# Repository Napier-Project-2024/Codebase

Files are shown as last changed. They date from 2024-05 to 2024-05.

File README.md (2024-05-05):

# Hexasense API v0.1

This repository contains the component parts of the prototype implementation of a proprioception system for the Vincross HEXA robot.
<br>
<br>
This project is developed by Group Project Team 104 on behalf of the We Are Robots Lab at Edinburgh Napier University as part of the Group Project Module 2023-24.
<br>
<br>
See [Hexasense Hardware](/Hexasense_Hardware) for the Hexasense Hardware implementation
<br>
See [Hexasense API](/Hexasense_API) for the Hexasense API implementation
<br>
See [Demo](/Demo) for a usage demonstration MIND SDK Project for the HEXA robot

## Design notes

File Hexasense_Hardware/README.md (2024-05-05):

# Hexasense API v0.1 - Hardware Implementation

This seems like it's going to be a dense document so, if you don't have one already, get yourself a coffee first.

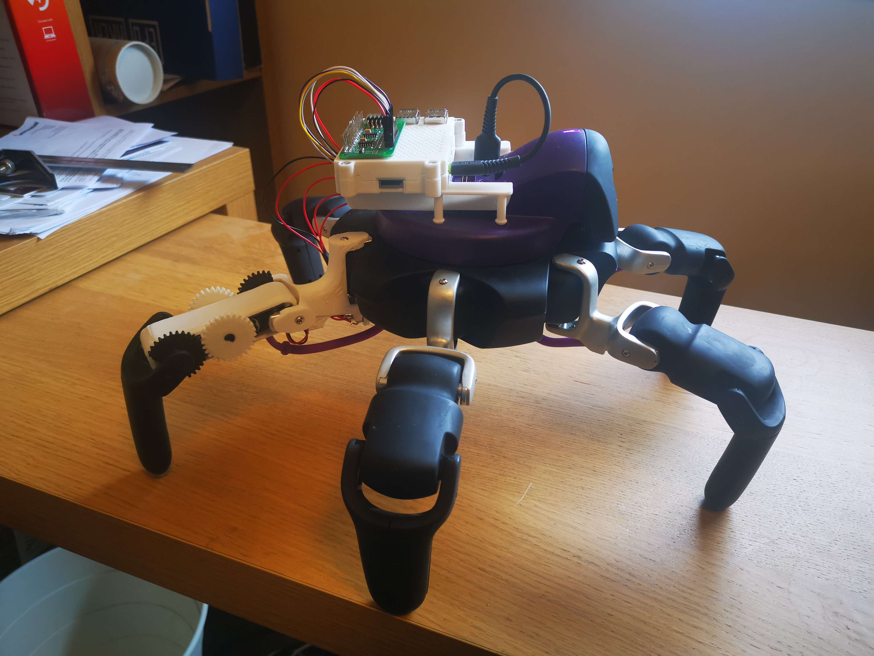
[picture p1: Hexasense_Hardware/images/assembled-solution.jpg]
Assembled Prototype


## Design Intent

The intention of this hardware design is to provide a means of sensing the position of the actuators of the HEXA robot whilst maintaining the ability to fully revert the robot to it's original factory state.<br>
Any instance where modification of the robot's hardware would be required, an appropriate 3D printed part has been designed and manufactured to integrate in place of the original robot hardware.<br>
It is also intended that the SBC component part of this system should function as an analogue for the HEXA robot to allow future integration of the Hexasense API software solution and ADC system directly with the HEXA robot itself, negating the need for the additional SBC hardware and potentially increasing the responsiveness of the API in use.<br>

## Hardware Description

The hardware implementation to add a proprioceptive sensing system to the HEXA Robot can be described as having three component parts to it's structure.
- A "Digital Twin" Data Processing & Relay System - Comprising of an off-the-shelf Raspberry Pi 4B SBC
- An ADC Measurement System - Comprising of a series of potentiometers mechanically coupled to the robot's actuators and an off-the-shelf ADC printed circuit board interfaced with the Data Processing & Relay System using the I2C protocol
- The Mechanical Hardware Assembly - A series of plastic parts manufactured using an FDM rapid prototyping process and designed to integrate the sensing system with the robot's hardware

These three component parts function together to deliver the desired actuator positional data required by the project.

### Raspberry Pi 4B SBC - The "Digital Twin"

This small single board computer provides a method of capturing the sensing data from the I2C bus and relaying it to the HEXA robot.
The SBC is configured to detect and connect to the HEXA robot's wifi access point automatically and begin broadcasting the sensing data through a network accessible implementation of the python fastAPI library. This will allow the API to be called by a Golang script in order to make use of the sensing data for proprioceptive purposes.

For detailed documentation of the Raspberry Pi 4B, please see the [Raspberry Pi 4B Documentation.](https://www.raspberrypi.com/documentation/computers/raspberry-pi.html)

### ADC Pi - Measurement System

The ADC Pi board is comprised of two MCP3424 ADC ICs and an bi-directional I2C Logic Level converter circuit which converts the Raspberry Pi's 3.3 volt logic level to
a 5 volt logic level suitbale for the MCP3424 ADCs. The ADCs can be queried by the Rapserry Pi over the I2C buss and will return the voltage value present
at each of it's sense pins.

For detailed documentation of the ADC Pi add-on board, please see the [AB Electronics](https://www.abelectronics.co.uk/) website for the [ADC Pi product.](https://www.abelectronics.co.uk/p/69/adc-pi)

### Potentiometers - Actuator Coupling

The prototype implementation uses three TT Electronics P090L-01F15BR10K 10 kilo-ohm linear potentiometers which function as voltage dividers. Each potentiometer has their CW and CCW pins tied to 5 volts and Ground respectively, while their W pin is tied to the respective sense pin of the ADC Pi baord. This allows for the rotation of the potentiometer to result in a change in voltage detected by the ADC IC as a voltage value between the 5 volts and 0 volts.

In principle, any value of potentiometer can be used in this manner, however it is important that the potentiometer selected has a Linear taper type, such that the voltage returned to the ADC at each rotational position of the potentiometer is proportional to the degree of rotation of the potentiometer, allowing the angle of 
rotation to be calculated accurately.

For detailed documentation of the TT Electronics P090L-01F15BR10K potentiometers, please see the TT Electronics [Product Page](https://www.ttelectronics.com/products/passive-components/potentiometers/p090l/) and [Datasheet.](https://www.ttelectronics.com/TTElectronics/media/ProductFiles/Datasheet/P090.pdf)

## Schematic Diagram of Electronic Components

This section describes the electronic connections between the component parts of the system only. 
For detailed schematic diagrams of the individual component parts of the system, please see the individual manufacturer's documentation and datasheets as directed above.

### Connecting the Raspberry Pi to the ADC Pi

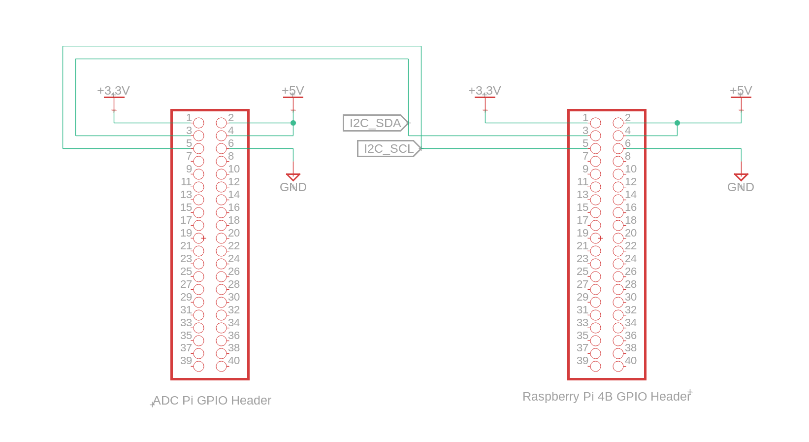
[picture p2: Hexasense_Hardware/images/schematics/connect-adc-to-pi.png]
Connecting the Raspberry Pi to the ADC Pi


The above schematic shows the connections required between the Raspberry Pi SBD and the ADC Pi add-on board for correct operation. 

Although both devices have 40-pin connectors, this is merely for the convenience of direct physical connection during development. In use, only five pin connections are required for correct interoperation of the devices.
The ADC Pi requires both 5v and 3.3v, as well as Ground connections to power the ADC ICs and the 3.3v to 5v logic level converters (as illustrated in the ADC Pi's board schematic). 
Data connection between the two devices is achieved using the I2C0 bus of the Raspberry Pi using the I2C0_SDA (pin 3) and I2C0_SDL (pin 5) connections.

### ADC Pi I2C Bus Address Setting

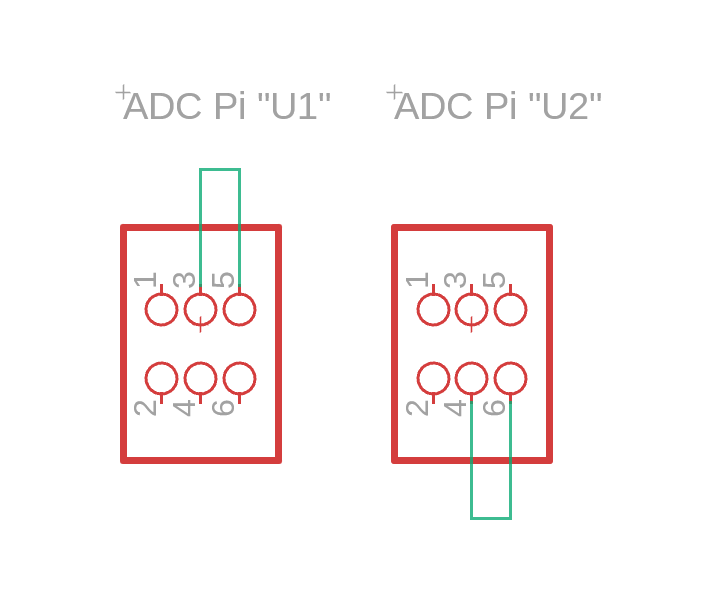
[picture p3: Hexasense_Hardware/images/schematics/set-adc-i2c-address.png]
Choosing I2C Bus Addresses


The above schematic shows the default I2C bus address selection setting for the ADC Pi.

I2C bus addressing of the two MCP3424 ICs is achieved using the "U1" and "U2" physical jumpers on the ADC Pi add-on board. This addressing system allows for a maximum of 8 possible individual chip addresses on the same I2C bus for these devices, allowing for a maximum of 4 ADC Pi add-on boards to be used simultaneously on the same I2C bus.
This would allow for a total of 32 ADC inputs to be addressed, which surpasses the required 19 inputs to implement proprioceptive sensing of all the leg actuators on the HEXA robot (3 actuaors per leg * 6 legs + input voltage reference measurement).
As our prototype only implements proprioception of a single leg currently, only 4 of the available ADC inputs are required for correct operation of the prototype system.

### Connecting the Potentiometers to the ADC Pi

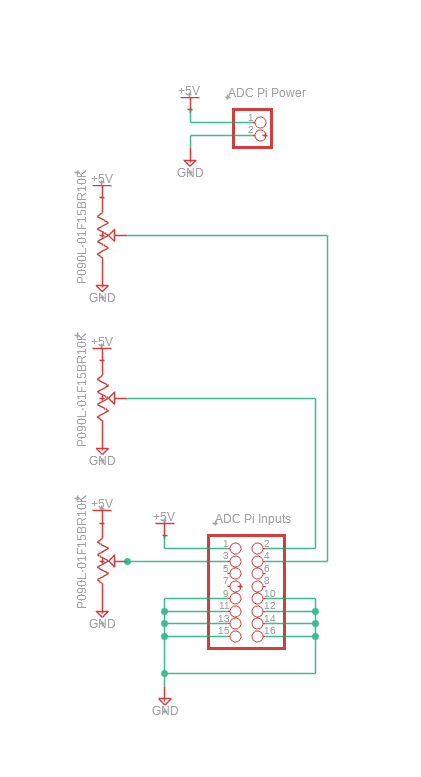
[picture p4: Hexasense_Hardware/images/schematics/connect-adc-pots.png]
Connecting Potentiometers to the ADC Pi


The above schematic shows the potentiometer connections required to implement proprioceptive sensing of three actuators on the HEXA robot.

In order to correctly scale the readings from each connected potentiometer to a floating point number between 0 and 1, we must be able to measure the maximum possible voltage that can be returned from a potentiometer to perform the scaling calculation. This is achieved by dedicating and ADC input solely to measuring the supply voltage of the system. Our software API implementation uses ADC input 1 to achieve this, thus it is imperitive that ADC input 1 be connected to the same 5v supply voltage to which the potentiometers are connected. This circuit design also accounts for situations where the supply voltage may fluctuate such that because the supply voltage is known, the scaling calculation will always return an accurate rotational position for each potentiometer within the operating voltage range of the ADC devices.

The potentiometers function as in-circuit variable voltage dividers. With their CCW pins tied to Ground and their CW pins tied to the supply voltage as shown, the voltage measured at the W pin of the potentiometer can be taken as a percentage value of the supply voltage. As the potentiometers selected have a linear taper type, a 50% rotational position of the potentiometer will always result in a measurement of 50% of the supply voltage at the potentiometer's W pin. Similarly due to a linear potentiometer taper type, a 5% rotational position of the potentiometer would also measure as 5% of the supply voltage at the W pin in this configuration. Given a perfectly linear potentiometer taper, this should result in accurate rotational position measurement of the potentiometer as a percentage of the total angular range of the potentiometer - in this case a percentage of 270 degrees of rotation.

## Mechanical Hardware Assembly

Full Assembly

The above animation shows the assembly of a complete set of the required parts to implement proprioceptive sensing on a single leg of the HEXA robot.

To allow for the addition of our proprioception system to the HEXA robot in a non-destructive and reversible manner, the design and manufacture of some mechanical components was required.
These components were designed using Autodesk's Fusion CAD software, and manufactured using FDM 3D Printing with a Creality Ender 3 V3 KE 3D printer.
Each of the mechanical parts required some design iteration and repeated protoype manufacturing to achieve the correct fit and functionality due to the mehcanical precision required and a lack of experience among the team members in using these tools and techniques.
Some of the design choices made during this process were made simply to prevent interference of mechanical parts of the robot during operation, specifically the choice to directly couple the hip actuator to the potentiometer, where the mid-leg assembly instead uses gearing to couple the potentiometers to the actuators instead.
The replacement assembly re-uses all of the stock robot's screws and fastenings.

### HEXA Hip Replacement

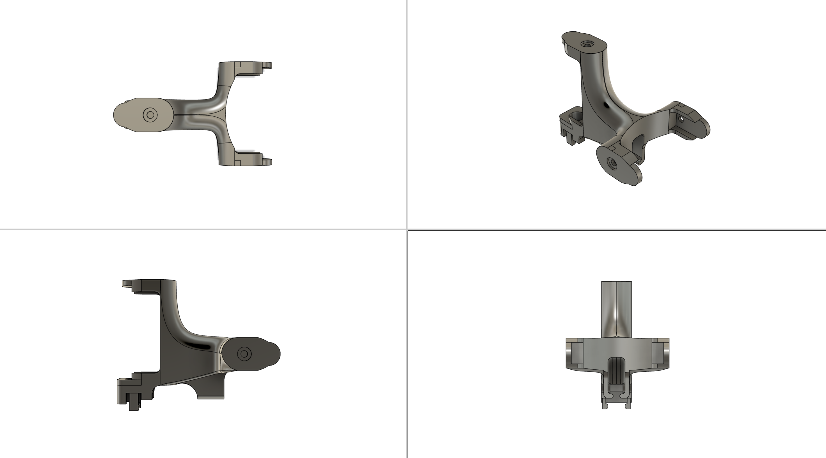
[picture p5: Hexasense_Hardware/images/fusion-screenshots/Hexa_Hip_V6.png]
Replacement Hip Model


The replacement part for the "hip" section of the HEXA's leg is a complicated geometry to reproduce successfully with a 3D printed part.
The layer orientation of the printed part i an important consideration to ensure the stringth of the part in this case, particularly in the potentiometer mount where the retention clips for the potentiometer will easily snap if the part is not printed on it's side with the layer lines running lenghtwise through the retention clips.
This orientation is depicted in the top left section of the above design image, where the layer lines would run horizontally through the re-oriented part.
Printing this part will require supports.

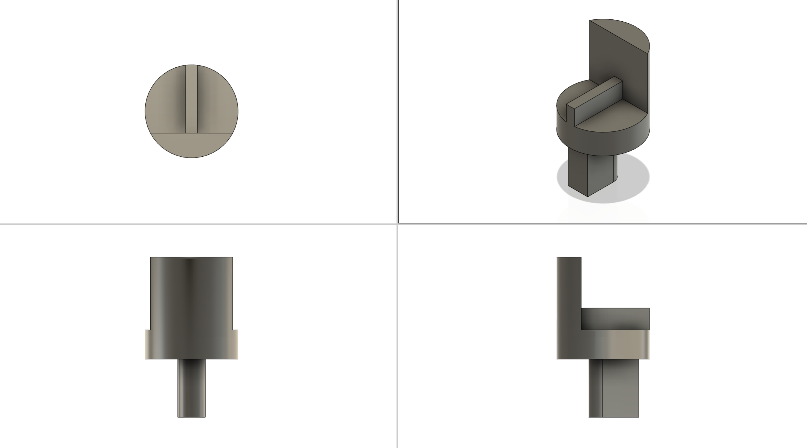
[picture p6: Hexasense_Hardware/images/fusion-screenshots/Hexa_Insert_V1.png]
Hip Potentiometer Coupling Insert


The potentiometer mearuing the "hip" joint position is coupled axially through the rotational centre of the joint directly to a "key" in the body of the potentiometer located in the centre bore of the free-running bearing on the servo motor body using the very small insert part depicted above.
This part is most successfully 3D printed upside-down when refrencing the above design image and will require printing supports.

### HEXA Mid Leg Replacement & Potentiometer Coupling Gears

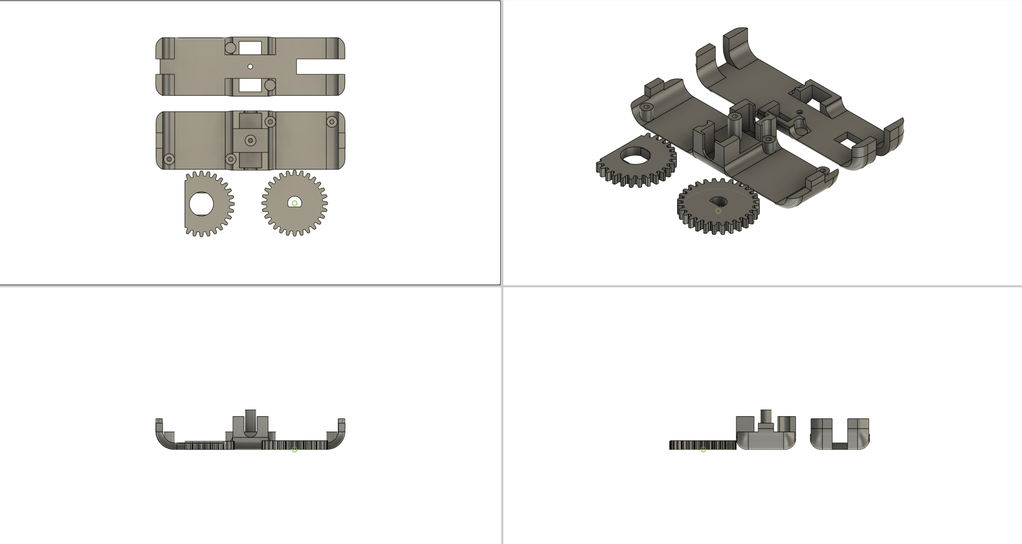
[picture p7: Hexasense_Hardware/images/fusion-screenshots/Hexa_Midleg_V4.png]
Mid Leg Assembly


The mid-leg assembly houses two potentiometers with independent gearing mechanisms to measure the positions of both the leg actuator, and the toe actuator. 
The two mechanisms are a mirror image of one-another, making the assembly procedure relatively simple.
Great care should be taken when assembling this section not to damage the wiring when attaching the Lid as the wiring loom ends up tightly packed through the section where the Lid screw is secured.

### SBC & ADC Mounting Solution

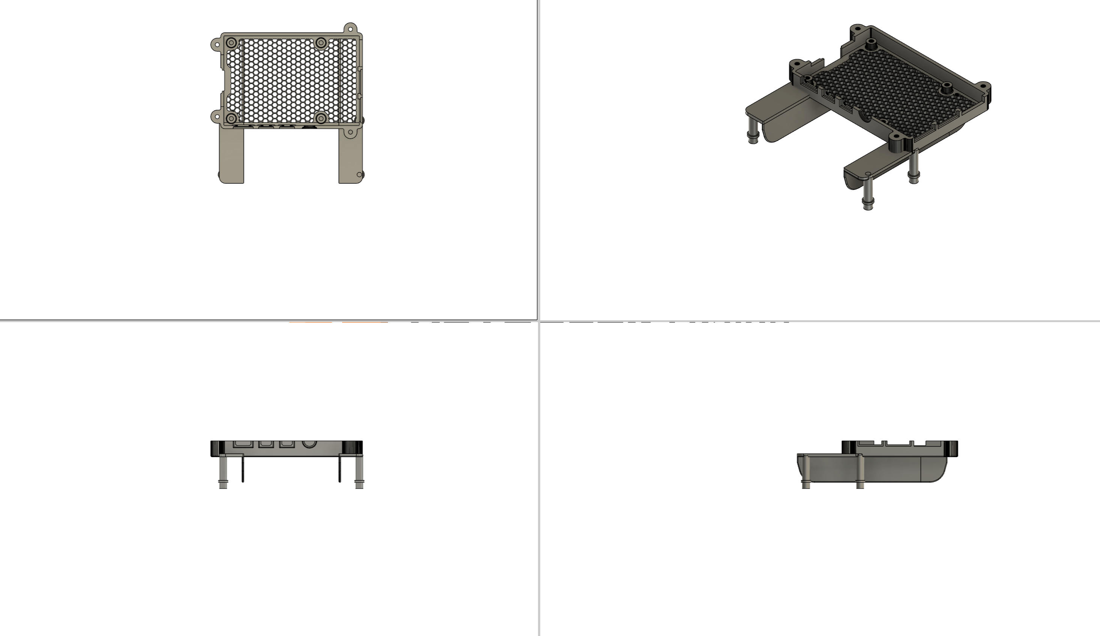
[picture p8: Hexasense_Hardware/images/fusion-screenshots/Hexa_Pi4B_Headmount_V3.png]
SBC & ADC Mounting Solution


The mounting solution for the SBC and ADC add-on board is based on a design for a Rapsberry Pi case created and distributed by Thingiverse user "mkellsy" which can be [found here](https://www.thingiverse.com/thing:3793664). 
This design was then adapted to allow easy mounting of the proprioception system directly to the HEXA robot in place of the factory head shell. This conveniently also allows the use of the HEXA robot's onboard USB port to power the proprioception system.

## 3D Printing Considerations

Our prototype parts were printed using a 0.2mm layer height in a combination of PLA and PETG. It was initially assumed that PLA might not be structurally strong enough, however during iteration and printing of parts for test fitting it was fount that PLA was of adequate strength for this use case.
Support structures will be required to print the Hip, Hip Insert and SBC/ADC Mounting Solution.
It is important that your printer is calibrated correctly to ensure dimensional accuracy of your parts as the designs supplied here require a 0.1mm dimensional tolerance to ensure they fit together correctly.
The total print time for a full set of the required parts using an Ender 3 V3 KE printer is 7 hours 14 minutes, as shown in the screenshot from Orca Slicer below.

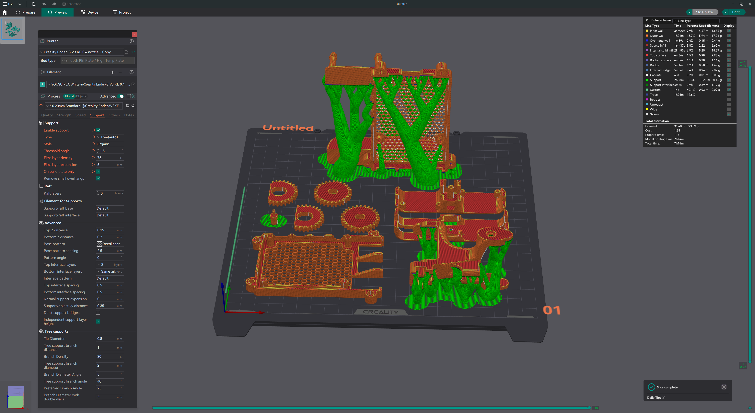
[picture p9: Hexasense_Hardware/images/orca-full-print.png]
Full Print Orca Slicer


The above Orca Slicer project file can be found [here](./models/orca-full-print.3mf), alongside the individual STL files for each part [here](./models).
The source project files from Autodesk Fusion can also be found [here](./fusion).
It is recommended you adapt the support structures, quality settings, and part orientation to suit your specific printer, however the above can be used as a reference.

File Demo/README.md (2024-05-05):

# Demonstration of Hexasense API Usage

This demo HEXA project shows the basic operation of the Hexasense API in the context of a Mind SDK Go script.
To execute this demo, the "APIdemo" folder and all it's contents should be copied to your ```~/go/src/mindsdk/``` directory and executed from inside the APIdemo directory using the command ```mind build && mind pack && mind run```

The Go script itself is found at ```/APIdemo/src/apidemo.go```

This simple script performs a full range motion on each of the specified leg's joints whilst calling the Hexasense API via HTTP and printing the API response JSON string to the console, a shown in the sample output below.
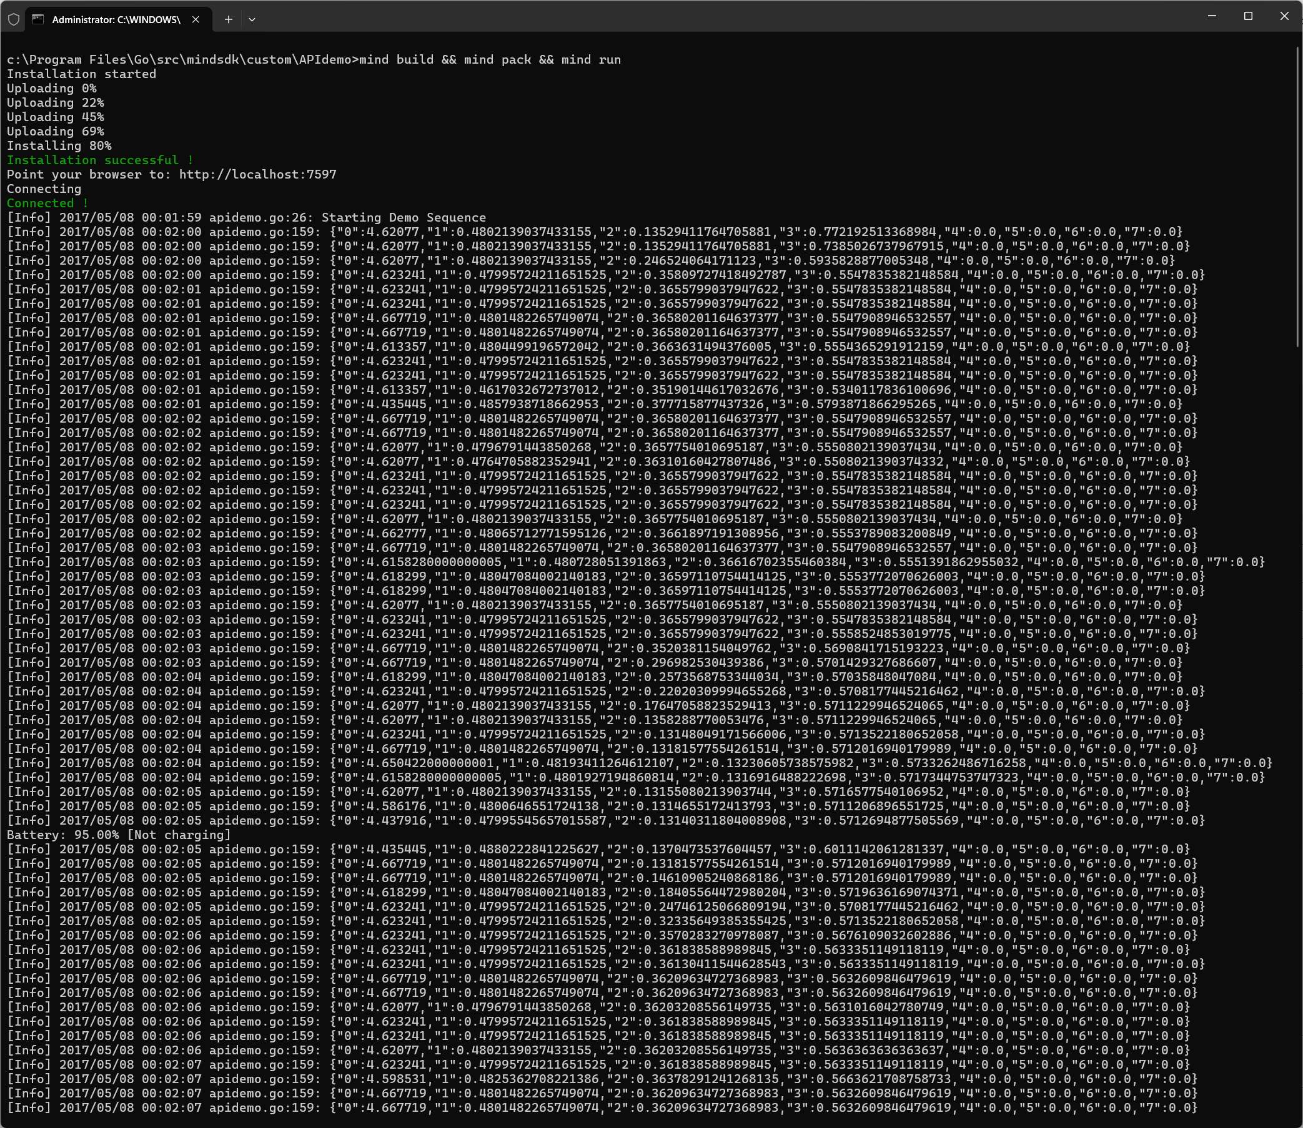
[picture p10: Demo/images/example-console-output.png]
Sample Console Output


## The Example callAPI() Function

This function demonstrates how to call the API from a Go script and store the response in a JSON format.
The example also prints this response to the console.

The callAPI function makes use of the "http", "ioutil", and "json" libraries which are imported alongside the required Mind SDK libraries as shown below.

```go
import (
	
	"mind/core/framework/drivers/hexabody"
	"mind/core/framework/log"
	"mind/core/framework/skill"
	"time"
	"net/http"
	"io/ioutil"
	"encoding/json"
)
```

The callAPI function begins by declaring the URL that the API calls are made to.
This can be changed to match your specific implementation of the API.

```go
// Set the URL from which the JSON will be retrieved
	url := "http://192.168.251.100:5000/returnValues" // The wifi network URL of the fastAPI instance
```

The function then issues an HTTP GET request to the specified URL, storing the request response and any error messsage.

```go
// Issue an HTTP GET to the URL
	req, err := http.Get(url)
```

The following IF statement handles any errors that are returned, printing the error message to the console.

```go
	// Handle any errors during the HTTP GET
	if err != nil {
		log.Info.Println("API Call Error:", err.Error())
		return
	}
```

When no errors are returned, the function then closes the HTTP response body.

```go
	// Close the HTTP response body
	defer req.Body.Close()
```

The HTTP response body is then read into a "body" variable and any errors reading the body are stored.

```go
	// Read in the response body
	body, readErr := ioutil.ReadAll(req.Body)
```

If an error is detected while reading in the HTTP response body, the error is printed to the console.

```go
	// Handle any HTTP response errors
	if readErr != nil {
		log.Info.Println("API Response Error:", err.Error())
		return
	}
```

The HTTP response body is then encoded into the JSON format.

```go
	// Encode the response body as JSON
	json.Marshal(body)
```

This JSON string can now be printed to the console.

```go
	// Log the JSON to the console
	log.Info.Print(string(body))
```

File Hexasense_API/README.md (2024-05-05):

# Hexasense API Documentation

The Hexasense API is built in the Python language and runs on a basic implementation of the [FastAPI Framework](https://fastapi.tiangolo.com/).

The API's main function is to respond to HTTP GET requests at the ```/returnValues``` URL with a JSON string containing the measured positions of each of the actuators in the HEXA robot's legs as a floating point value between 0 and 1.

The API will also respond to root requests with an ```index.html``` page which will display these values live in a web browser window.

These functions are achieved by using the [ADCPi library](https://github.com/abelectronicsuk/ABElectronics_Python_Libraries/tree/master/ADCPi) provided by [ABElectronics](https://www.abelectronics.co.uk/) to interface with their [ADC Pi](https://www.abelectronics.co.uk/p/69/adc-pi) 8-channel analogue to digital converter board to perform voltage readings on the ADC inputs.

The API is served using the [Uvicorn ASGI web server](https://www.uvicorn.org/) which is configured to run as a daemon upon system boot.

## Installation & Setup

## The API Script

The required libraries and frameworks are imported.

```python
# Imports
from fastapi import FastAPI
from starlette.responses import FileResponse 
import datetime
import json

# Load from the ADCPi library provided by ABElectronics
# Try the import
try:
    from ADCPi import ADCPi

# Handle any errors
except ImportError:
    print("Failed to import ADCPi from python system path")
    print("Importing from parent folder instead")
    try:
        import sys
        sys.path.append('..')
        from ADCPi import ADCPi
    except ImportError:
        raise ImportError(
            "Failed to import library from parent folder")
```

The ADC Pi library requires the hexadecimal I2C bus addressess of the ADC devices and the sampling bit depth to be defined.
In this instance we are using the default addresses and a bit depth of 12.

```pyhton
# Define the ADC devices' I2C addresses and sampling bit-depth
adc0 = ADCPi(0x68, 0x69, 12)
```

The FastAPI application is then defined

```python
# Define the fastAPI application
app = FastAPI()
```

Next, the root directory response of the API is defined. This function returns the ```index.html``` live data view webpage as a file response.

```python
# Define the root directory reponse of the API
@app.get("/")
async def root():    
    # Return the index.html file
    return FileResponse('index.html')
```

Finally, we define the ```/returnValues``` API response.

This function has two parts, one that creates the JSON formatted response string, and one that converts the ADC input values to a floating point value between 0 and 1.

First, the voltage value present at ADC input 1 is read as a base voltage to perform the required conversions.

```python
        # Read a base voltage from ADCPi pin 1 - this measures the supply rail voltage to allow scaling of the actuator sensing measurements between 0 (ground voltage) and 1 (supply rail voltage)     
        baseVoltage = adc0.read_voltage(1)
```

Then a ```createValues``` function is defined which assembles the JSON response by calling a ```convert``` function and supplying the ADC voltage reading for the relevant input and the base voltage reading as parameters.

```python
        # Read all the actuator sensing data into a single sample dictionary
        # Convert each of the sensed voltages into the scaled 0-1 range 
        def createValues(baseVoltage):
            values = {
            0 : baseVoltage,
            1 : convert(adc0.read_voltage(2), baseVoltage),
            2 : convert(adc0.read_voltage(3), baseVoltage),
            3 : convert(adc0.read_voltage(4), baseVoltage),
            4 : convert(adc0.read_voltage(5), baseVoltage),
            5 : convert(adc0.read_voltage(6), baseVoltage),
            6 : convert(adc0.read_voltage(7), baseVoltage),
            7 : convert(adc0.read_voltage(8), baseVoltage)  
        }
```

The ```convert``` function is then defined, taking two input parameters - an ADC input voltage, and a base voltage.

```python
        # Define a function to scale the sensing data
        def convert(input, base):
            # Try the conversion
            try:
                output = input/base
            
            # Handle Divide By Zero exceptions
            except:
                output = 0
            
            # Return the scaled sensing data
            return output
```

This function divides the ADC input voltage by the base voltage to arrive at a value between 0 and 1.
To prevent divide-by-zero errors, a try/catch is used to account for the situation where the base voltage is read in as zero which may occur if there is a wiring error in the ADC circuit. This exception is handled by simply outputing a zero value in all instances.

The entire ```returnValues``` function then returns the assembled JSON string.

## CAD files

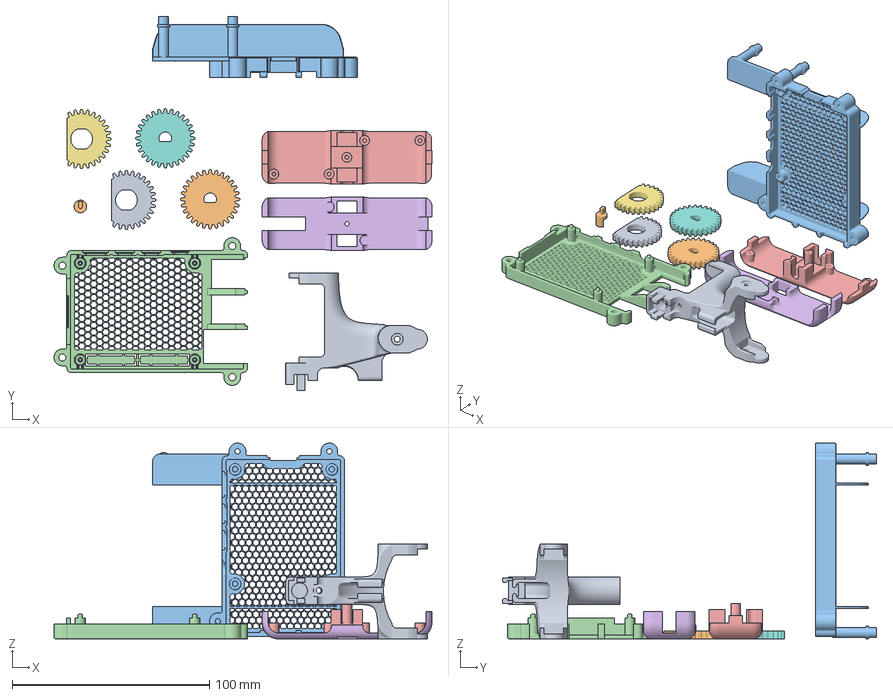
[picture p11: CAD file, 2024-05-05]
Hexasense_Hardware/models/orca-full-print.3mf
191.5 x 189.5 x 99.3 mm
Hexa_Hip_V6 v2.stl
Hexa_Insert_V1 v5.stl
Hexa_Pi4B_Headmount v3.stl
Hexa_Pi4B_Headmount_Lid.STL
MidLeg V4 v1.stl_1
MidLeg V4 v1.stl_2
MidLeg V4 v1.stl_3 x 2
MidLeg V4 v1.stl_4 x 2

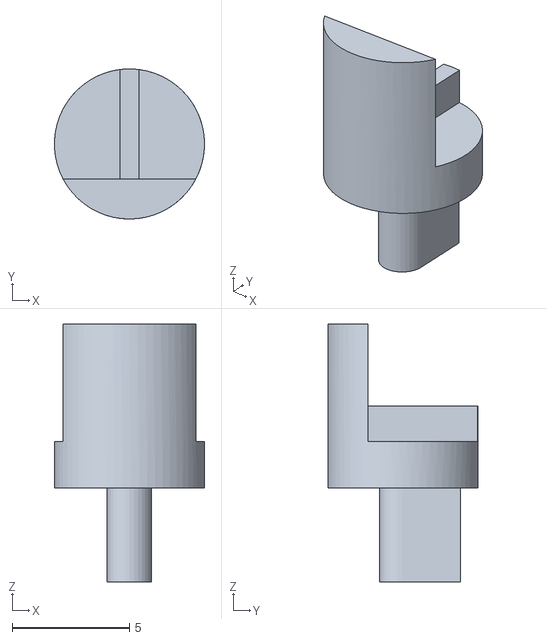
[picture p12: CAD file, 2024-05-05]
Hexasense_Hardware/models/Hexa_Insert_V1 v5.stl
6.40 x 6.40 x 11.0

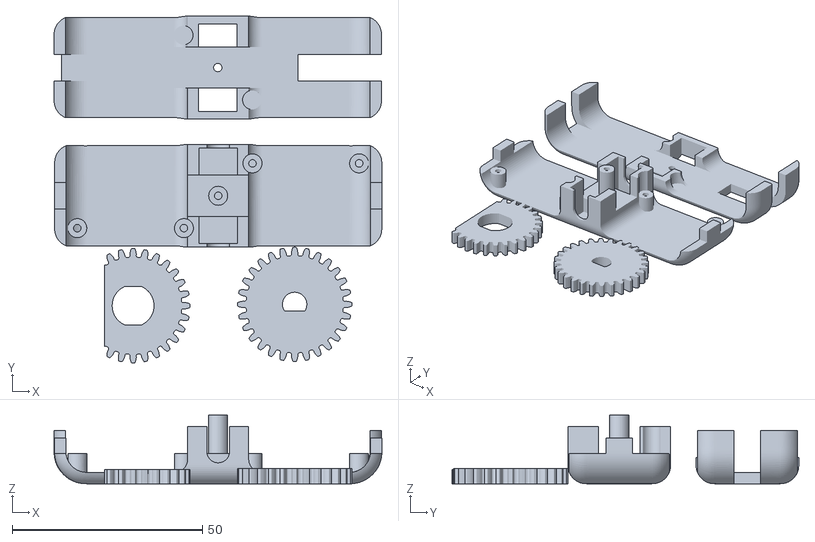
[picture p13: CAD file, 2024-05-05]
Hexasense_Hardware/models/MidLeg_V4_v1.stl
86.1 x 91.0 x 18.0

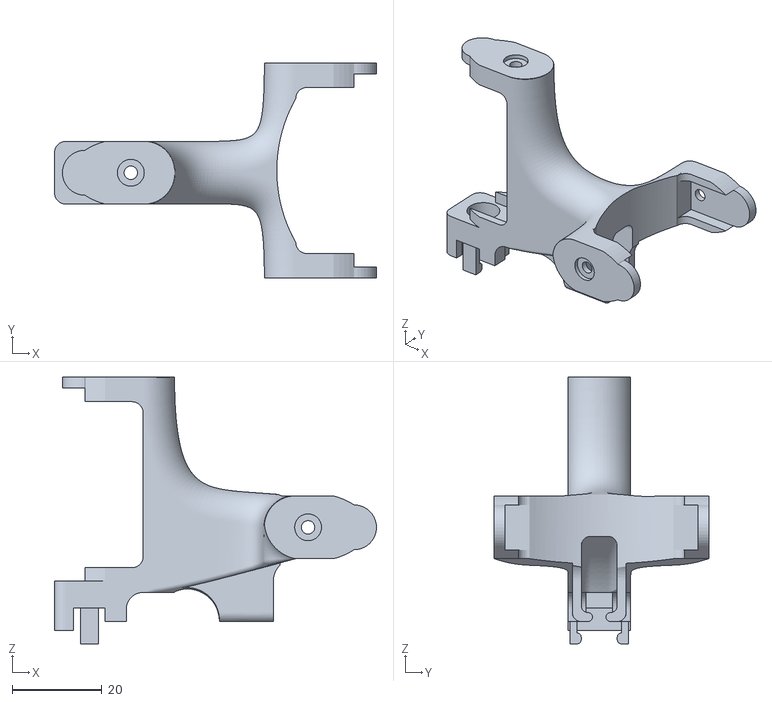
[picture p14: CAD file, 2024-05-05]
Hexasense_Hardware/models/Hexa_Hip_V6 v2.stl
71.8 x 48.0 x 59.5

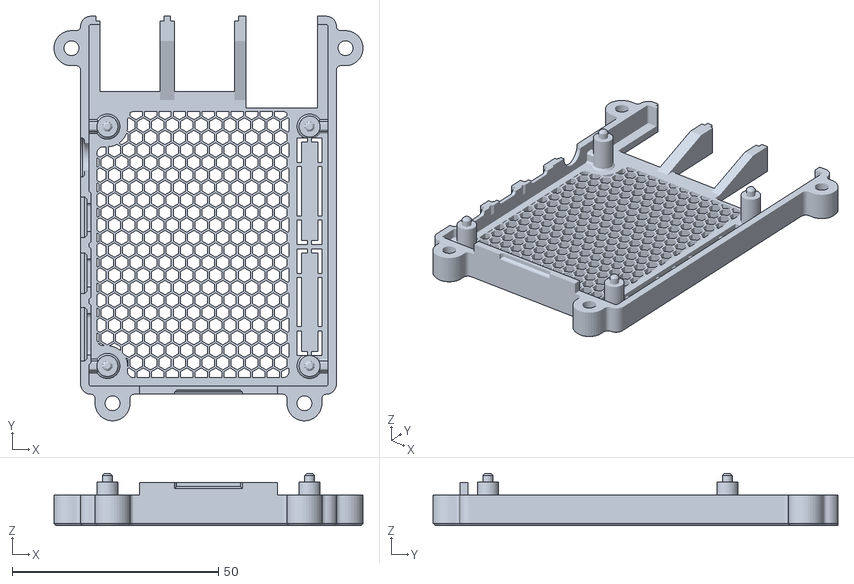
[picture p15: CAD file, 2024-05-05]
Hexasense_Hardware/models/Hexa_Pi4B_Headmount_Lid.STL
74.9 x 98.0 x 12.7

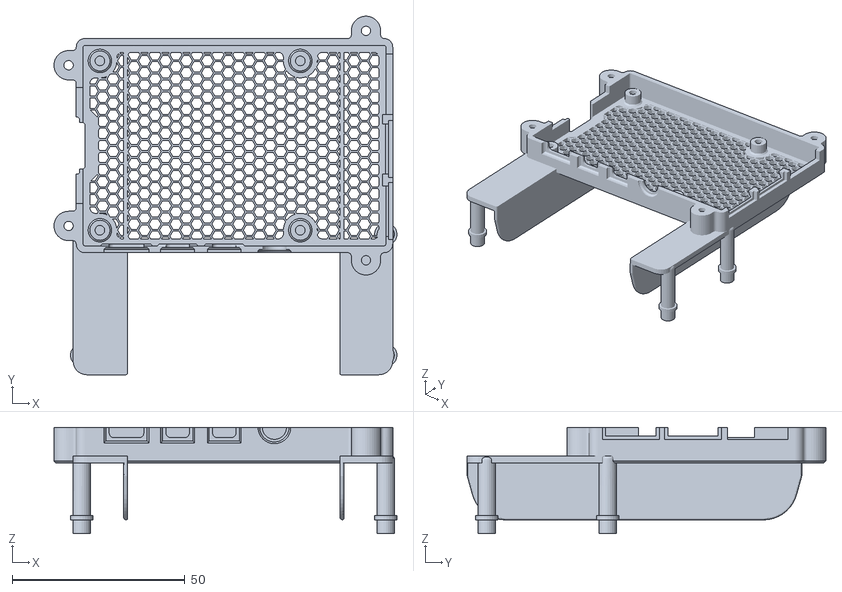
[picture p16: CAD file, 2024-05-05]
Hexasense_Hardware/models/Hexa_Pi4B_Headmount v3.stl
99.3 x 103.8 x 30.8

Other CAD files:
Hexasense_Hardware/fusion/Hexa_Hip_V6 v2.f3d
Hexasense_Hardware/fusion/Hexa_Insert_V1 v5.f3d

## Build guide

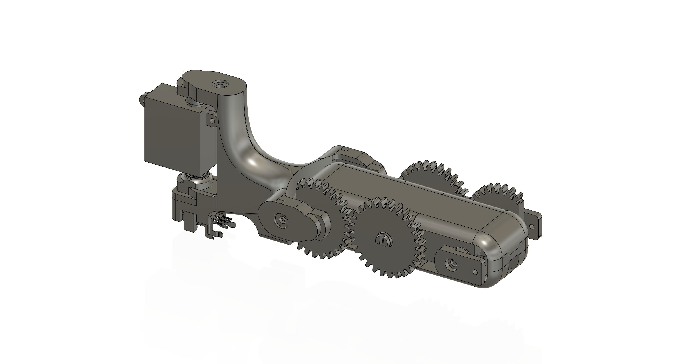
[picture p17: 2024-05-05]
Hexasense_Hardware/images/fusion-screenshots/full-assembly.png

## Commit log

2024-03-29 added read voltage script
2024-03-29 new test.py with baked in ADC demo script
2024-03-29 spill adc reads into subprocess
2024-04-11 duplicated current version of API to Hexasense API folder
2024-04-11 add readme, images & fusion projects to hardware folder
    [Hexa_Hip_V6 v2.f3d, Hexa_Hip_V6 v2.stl, Hexa_Insert_V1 v5.f3d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]
2024-04-11 added headmount lid STL file
    [Hexa_Pi4B_Headmount_Lid.STL]
2024-04-12 added schematics, added to hardware readme
2024-04-12 schematics section of hardware readme completed.
2024-04-12 added img of complete assembly
2024-04-12 added fusion screenshots to hardware readme
    [MidLeg_V4_v1.stl]
2024-04-18 complete hardware readme
    [orca-full-print.3mf]
